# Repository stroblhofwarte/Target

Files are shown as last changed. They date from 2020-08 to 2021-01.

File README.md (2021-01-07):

# TargetClient
Target(Astronomy) is a small WiFi-Handbox to control a telecope mount via INDI. 
This box is running with battery and does not have any wire to the telecope mount. 
This box consists out of a electronic board, a ESP8266 firmware (arduino IDE) and a 
Qt5 application bridging the handbox to the INDI mount. The handbox provides four keys 
for N,S,W and E, one slew speed key with three LED's and a function key which change 
the N,S,W and E key to Focuser 1 in and out and Focuser 2 in and out 
(not tested yet, I don't have any motor focuser).

# Prerequist (Ubuntu)

```
sudo apt install build-essential
sudo apt install cmake
sudo apt install qt5-default
sudo apt install zlib1g-dev
sudo apt install libcfitsio-dev
```
Installation of the INDI lib development package:
```
sudo apt-add-repository ppa:mutlaqja/ppa
sudo apt update
sudo apt install libindi-dev
```

# How to build

```
cd ~/_develop/

git clone https://github.com/stroblhofwarte/Target.git

mkdir -p ~/_develop/build/targetclient

cd ~/_develop/build/targetclient

cmake -DCMAKE_INSTALL_PREFIX=/usr -DCMAKE_BUILD_TYPE=Release ~/_develop/Target/targetclient

make -j4

sudo cp TargetClient <WHERE/EVER/YOU/WANT>
```

# ASCOM TargetBridge

The new Version of the Target_Astronomy_.ino firmware (from 6.01.2021, ./targetclient/arduino/Target_Astronomy_) is supported by the ASCOM TargetBridge. This version of the firmware is
not supported by the INDI driver anymore. 
The ASCOM TargetBridge adds support for a Win10 based observatory setup. With the TargetBridge application the Target handcontroler 
box can be used to control the mount and the focuser together with the imaging software (e.g. N.I.N.A.). To reach this the ASCOM Hub must
be setup for devices not supporting a multiconnection. The ASCOM Hub must be setup only once. After setup the TargetBridge and/or the imaging
software will startup the hub automatically.

For some convenience four focuser positions (for absolute focuser only) can be marked. This can be used to switch the focal plane between a 
imaging setup with CCD and a visual setup easily.

The ASCOM TargetBridge is written in C# (VisualStudio 2019) and requires the ASCOM development libs to compile properly. 
An precompiled msi package will follow soon.

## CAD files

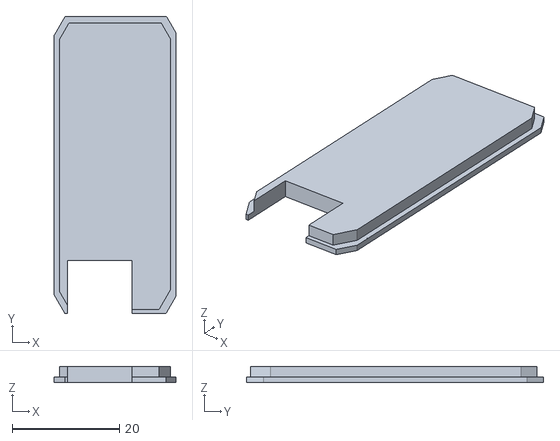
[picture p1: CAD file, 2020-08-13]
electronic/Front.stl
22.7 x 55.3 x 3.00

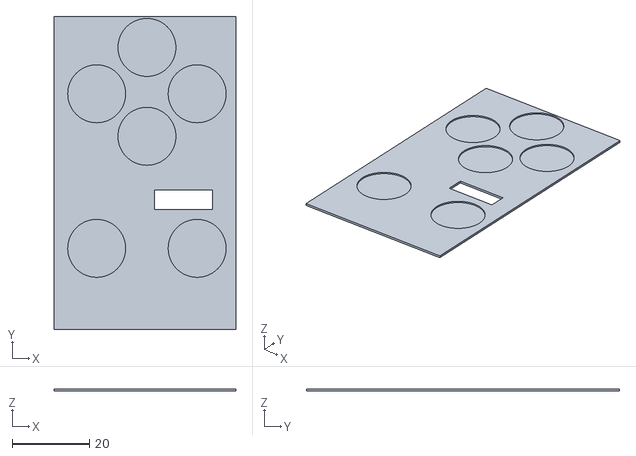
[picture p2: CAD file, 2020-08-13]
electronic/keymap.stl
47.0 x 81.0 x 0.6

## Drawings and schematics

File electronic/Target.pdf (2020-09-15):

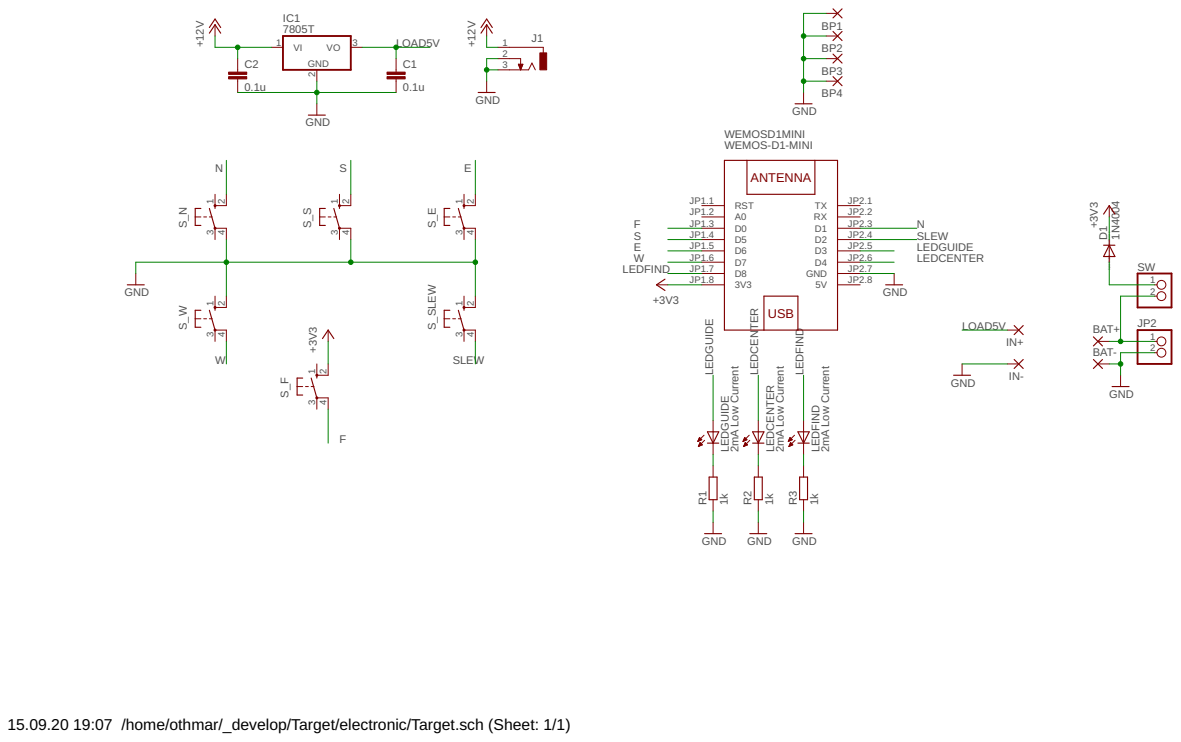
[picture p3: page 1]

15.09.20 19:07 /home/othmar/_develop/Target/electronic/Target.sch (Sheet: 1/1)

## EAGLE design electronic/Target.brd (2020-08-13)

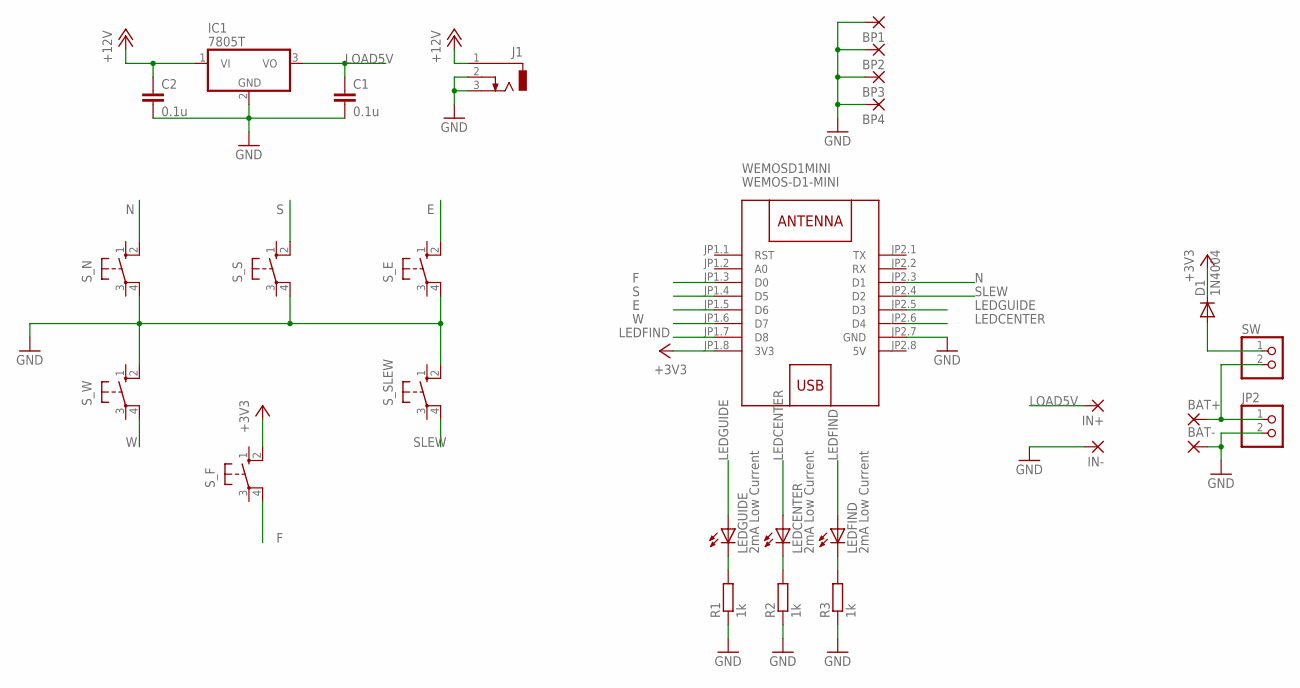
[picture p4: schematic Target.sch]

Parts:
BAT+: 2,15/1,0
BAT-: 2,15/1,0
BP1, BP2, BP3, BP4: 3,81/1,4
C1, C2: 0.1u; C025_050-025X075
D1: 1N4004; DO41-10
IC1: 7805T; TO220H
IN+: 2,15/1,0
IN-: 2,15/1,0
J1: DCJ0303
JP2: PINHD-1X2; 1X02
LEDCENTER: 2mA Low Current; LED3MM
LEDFIND: 2mA Low Current; LED3MM
LEDGUIDE: 2mA Low Current; LED3MM
R1, R2, R3: 1k; 0204/7
SW: PINHD-1X2; 1X02
S_E: 40-XX; B3F-40XX
S_F: 40-XX; B3F-40XX
S_N: 40-XX; B3F-40XX
S_S: 40-XX; B3F-40XX
S_SLEW: 40-XX; B3F-40XX
S_W: 40-XX; B3F-40XX
WEMOSD1MINI: WEMOS-D1-MINI

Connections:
5V: WEMOSD1MINI.JP2.8 (5V)
+3V3: D1.C, S_F.2 (S1), WEMOSD1MINI.JP1.8 (3V3)
+12V: C2.1, IC1.1 (VI), J1.1
E: S_E.2 (S1), WEMOSD1MINI.JP1.5 (D6)
F: S_F.4 (P1), WEMOSD1MINI.JP1.3 (D0)
GND: BAT-.1, BP1.1, BP2.1, BP3.1, BP4.1, C1.2, C2.2, IC1.2 (GND), IN-.1, J1.2, J1.3, JP2.2, R1.1, R2.1, R3.1, S_E.4 (P1), S_N.4 (P1), S_S.4 (P1), S_SLEW.2 (S1), S_W.2 (S1), WEMOSD1MINI.JP2.7 (GND)
LEDCENTER: LEDCENTER.A, WEMOSD1MINI.JP2.6 (D4)
LEDFIND: LEDFIND.A, WEMOSD1MINI.JP1.7 (D8)
LEDGUIDE: LEDGUIDE.A, WEMOSD1MINI.JP2.5 (D3)
LOAD5V: C1.1, IC1.3 (VO), IN+.1
N: S_N.2 (S1), WEMOSD1MINI.JP2.3 (D1)
unnamed: LEDGUIDE.K (C), R1.2
unnamed: LEDCENTER.K (C), R2.2
unnamed: LEDFIND.K (C), R3.2
unnamed: BAT+.1, JP2.1, SW.2
unnamed: D1.A, SW.1
S: S_S.2 (S1), WEMOSD1MINI.JP1.4 (D5)
SLEW: S_SLEW.4 (P1), WEMOSD1MINI.JP2.4 (D2)
W: S_W.4 (P1), WEMOSD1MINI.JP1.6 (D7)

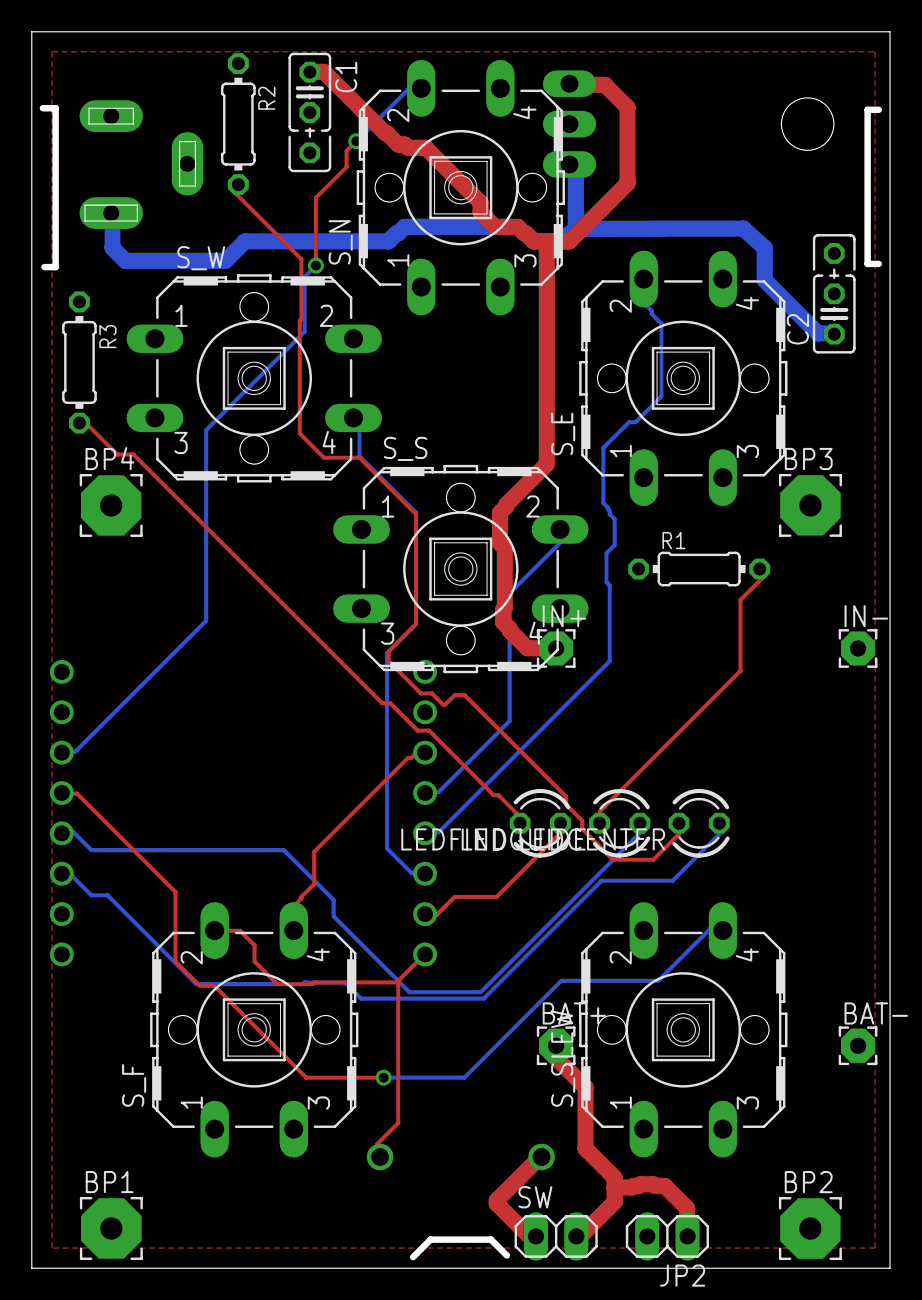
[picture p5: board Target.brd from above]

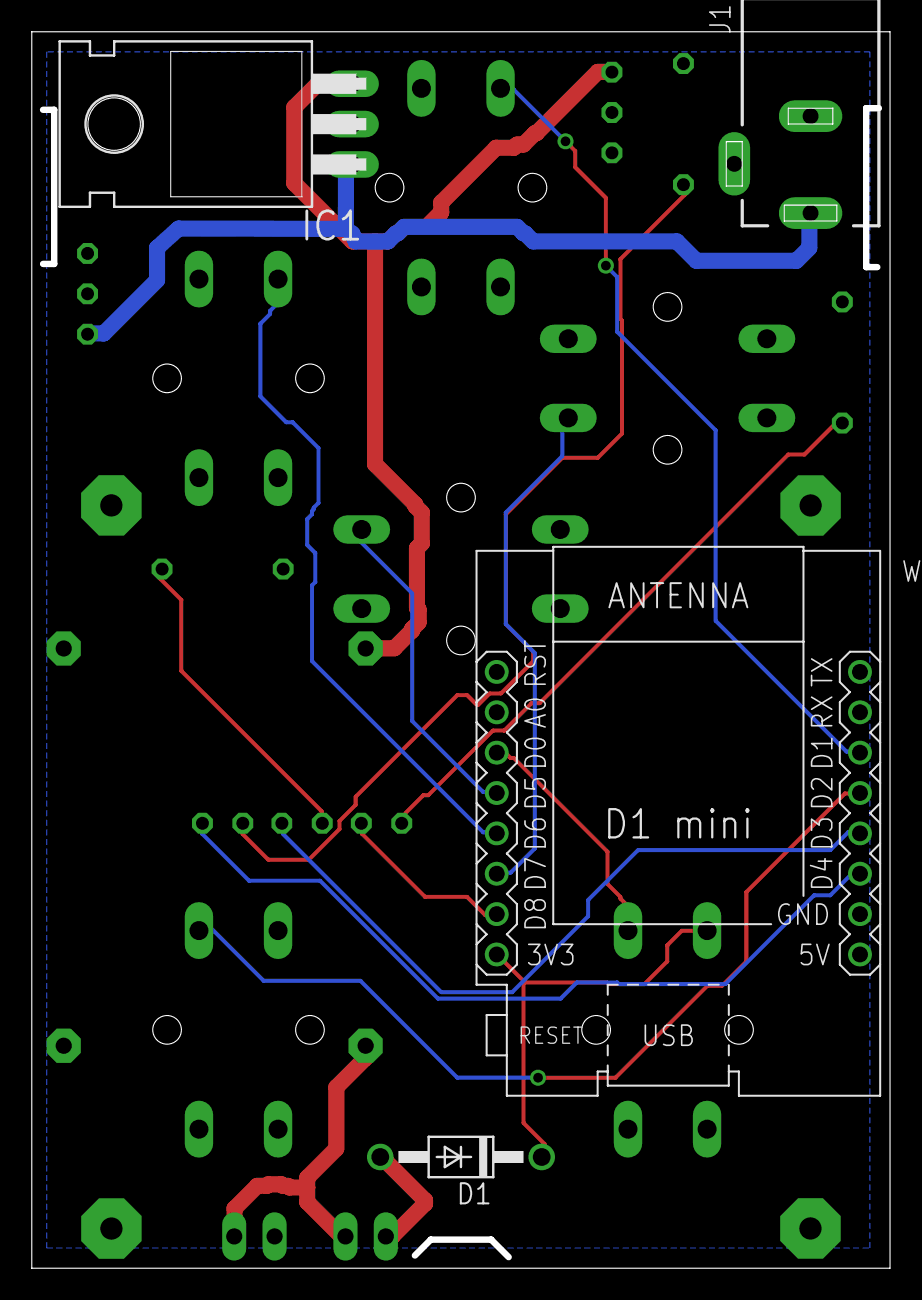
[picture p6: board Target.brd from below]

Board: 2 copper layers, 54.0 x 77.8 mm, 28 parts (4 on the bottom side), 18 nets.

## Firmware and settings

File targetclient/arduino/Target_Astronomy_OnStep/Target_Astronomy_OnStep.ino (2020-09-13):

/****************************************************************************************************************************
 * Target(Astronomy) control box
 * 
 * Software of the handcontrol box connected to a OnStep WiFi board.
 * This program will send the key presses of N,S,W,E,Func and Slew via TCP/IP.
 * 
 * It use the port 9998!
 * 
 * 
 * The startingpoint of this software was the ConfigOnStartup.ino example for ESP8266/ESP32 boards. 
 * 
 * 
 * Orginal Header:
 * 
 * ConfigOnStartup.ino
 * For ESP8266 / ESP32 boards
 *
 * ESP_WiFiManager is a library for the ESP8266/ESP32 platform (https://github.com/esp8266/Arduino) to enable easy
 * configuration and reconfiguration of WiFi credentials using a Captive Portal. Inspired by:
 * http://www.esp8266.com/viewtopic.php?f=29&t=2520
 * https://github.com/chriscook8/esp-arduino-apboot
 * https://github.com/esp8266/Arduino/blob/master/libraries/DNSServer/examples/CaptivePortalAdvanced/
 *
 * Forked from Tzapu https://github.com/tzapu/WiFiManager
 * and from Ken Taylor https://github.com/kentaylor
 * 
 * Built by Khoi Hoang https://github.com/khoih-prog/ESP_WiFiManager
 * Licensed under MIT license
 * Version: 1.0.4
 *
 * Version Modified By   Date      Comments
 * ------- -----------  ---------- -----------
 *  1.0.0   K Hoang      07/10/2019 Initial coding
 *  1.0.1   K Hoang      13/12/2019 Fix bug. Add features. Add support for ESP32
 *  1.0.4   K Hoang      07/01/2020 Use ESP_WiFiManager setHostname feature
 *  1.0.5   K Hoang       15/01/2020 Add configurable DNS feature. Thanks to @Amorphous of https://community.blynk.cc
 *****************************************************************************************************************************/

#include <FS.h>  

 /**************************************************************************************
  * 
  * Changelog:
  * 
  * 24.06.2020: Initial setup of the software.
  * 12.09.2020: Branch for development of a OnStep WiFi client.
  * 
  * 
  * ************************************************************************************/

//#define DEBUG //"Schalter" zum aktivieren

#ifdef DEBUG
#define DEBUG_PRINT(x) Serial.print(x)
#define DEBUG_PRINTLN(x) Serial.println(x)
#define AP_TIMEOUT 30
#else
#define DEBUG_PRINT(x)
#define DEBUG_PRINTLN(x)
#define AP_TIMEOUT 60
#endif
  
//For ESP32, To use ESP32 Dev Module, QIO, Flash 4MB/80MHz, Upload 921600

//Ported to ESP32
#ifdef ESP32
  #include <esp_wifi.h>
  #include <WiFi.h>
  #include <WiFiClient.h>

  #define ESP_getChipId()   ((uint32_t)ESP.getEfuseMac())

  #define LED_ON      HIGH
  #define LED_OFF     LOW  
#else
  #include <ESP8266WiFi.h>          //https://github.com/esp8266/Arduino
  //needed for library
  #include <DNSServer.h>
  #include <ESP8266WebServer.h>  

  #define ESP_getChipId()   (ESP.getChipId())

  #define LED_ON      HIGH
  #define LED_OFF     LOW
#endif

// SSID and PW for Config Portal
String ssid = "TargetHandbox_" + String(ESP_getChipId(), HEX);
const char* password = "88888888";

// SSID and PW for your Router
String Router_SSID;
String Router_Pass;

// Use false if you don't like to display Available Pages in Information Page of Config Portal
// Comment out or use true to display Available Pages in Information Page of Config Portal
// Must be placed before #include <ESP_WiFiManager.h> 
#define USE_AVAILABLE_PAGES     false

#include <ESP_WiFiManager.h>              //https://github.com/khoih-prog/ESP_WiFiManager
#include <ArduinoJson.h>                  //https://github.com/bblanchon/ArduinoJson

/******************************************************************
 * 
 *  Hardwaredefinition for Target(Astronomy):
 *  
 *  
 */

#define K_N           D1
#define K_S           D5
#define K_W           D7
#define K_E           D6
#define K_F           D0
#define K_SLEW        D2
#define LEDGUIDE      D8       // OUT
#define LEDCENTER     D3       // OUT
#define LEDFIND       D4       // OUT

#define KEY_NONE      0
#define KEY_N         1
#define KEY_S         2
#define KEY_W         3
#define KEY_E         4
#define KEY_FUNC      5
#define KEY_F1IN      6
#define KEY_F1OUT     7
#define KEY_F2IN      8
#define KEY_F2OUT     9
#define KEY_SLEW      10

/******************************************************************/
typedef struct
{
    char id[24];
    unsigned char cmd;
} _KEY_DATA;
char MoveNorth[5] = ":Mn#";
char MoveSouth[5] = ":Ms#";
char MoveWest[5] = ":Mw#";
char MoveEast[5] = ":Me#";
char MoveStop[5] = ":Q#";
char Center[5] = ":RC#";
char Guide[5] = ":RG#";
char Find[5] = ":RM#";
char Max[5] = ":RS#";
char Focus1In[5] = ":F+#";
char Focus1Out[5] = ":F-#";
char Focus1Stop[5] = ":FQ#";

int SlewGuide = 1;
int SlewCenter = 2;
int SlewFind = 3;
int SlewMax = 4;

_KEY_DATA g_data;
/******************************************************************
 * Target(Astronomy)
 */
unsigned long g_previousMillis = 0;
const long g_keyScanInterval = 100; //ms
int g_lastKey;

int g_slewrate = SlewMax;

#define ONSTEP_PORT 9998
WiFiClient g_client;
IPAddress IPudp (255, 255, 255, 255); // Sending via broadcast
IPAddress g_host;

char my_ip[32]   = "10.42.0.10";
char my_gw[32]   = "10.42.0.10";
char my_mask[32] = "255.255.255.0";
char my_host[32] = "192.168.0.1";


/*******************************************************************/

//default custom static IP
char static_ip[16] = "192.168.0.42";
char static_gw[16] = "192.168.0.1";
char static_sn[16] = "255.255.255.0";
char static_host[16] = "192.168.0.1";

//flag for saving data
bool g_shouldSaveConfig = false;

//callback notifying us of the need to save config
void saveConfigCallback () {
  DEBUG_PRINTLN("Should save config");
  g_shouldSaveConfig = true;
}


void heartBeatPrint(void)
{
  static int num = 1;

#ifdef DEBUG
  if (WiFi.status() == WL_CONNECTED)
    DEBUG_PRINT("H");        // H means connected to WiFi
  else
    DEBUG_PRINT("F");        // F means not connected to WiFi
#endif

  if (num == 80) 
  {
    DEBUG_PRINTLN();
    num = 1;
  }
  else if (num++ % 10 == 0) 
  {
    DEBUG_PRINT(" ");
  }
} 

void check_status()
{
  static ulong checkstatus_timeout = 0;

  //KH
  #define HEARTBEAT_INTERVAL    10000L
  // Print hearbeat every HEARTBEAT_INTERVAL (10) seconds.
  if ((millis() > checkstatus_timeout) || (checkstatus_timeout == 0))
  {
    heartBeatPrint();
    checkstatus_timeout = millis() + HEARTBEAT_INTERVAL;
  }
}

void ReadFilesystem()
{
  //read configuration from FS json
  Serial.println("mounting FS...");

  if (SPIFFS.begin()) 
  {
    DEBUG_PRINTLN("mounted file system");
    if (SPIFFS.exists("/config.json")) 
    {
      //file exists, reading and loading
      DEBUG_PRINTLN("reading config file");
      File configFile = SPIFFS.open("/config.json", "r");
      if (configFile) 
      {
        DEBUG_PRINTLN("opened config file");
        size_t size = configFile.size();
        // Allocate a buffer to store contents of the file.
        std::unique_ptr<char[]> buf(new char[size]);

        configFile.readBytes(buf.get(), size);
        DynamicJsonBuffer jsonBuffer;
        JsonObject& json = jsonBuffer.parseObject(buf.get());
        json.printTo(Serial);
        if (json.success()) 
        {
          DEBUG_PRINTLN("\nparsed json");
          if(json["ip"]) 
          {
            DEBUG_PRINTLN("setting custom ip from config");
            strcpy(static_ip, json["ip"]);
            strcpy(static_gw, json["gateway"]);
            strcpy(static_sn, json["subnet"]);
            strcpy(static_host, json["host"]);
            DEBUG_PRINTLN(static_ip);
          } 
#ifdef DEBUG
          else {
            DEBUG_PRINTLN("no custom ip in config");
          }
#endif
        } 
#ifdef DEBUG
        else {
          DEBUG_PRINTLN("failed to load json config");
        }
#endif
      }
    }
  } 
#ifdef DEBUG
  else {
    Serial.println("failed to mount FS");
  }
#endif
  //end read
}

void setup() 
{
  /* Target(Astronomy) hardware setup */


  pinMode(K_N,      INPUT_PULLUP);
  pinMode(K_S,      INPUT_PULLUP);
  pinMode(K_W,      INPUT_PULLUP);
  pinMode(K_E,      INPUT_PULLUP);
  pinMode(K_SLEW,   INPUT_PULLUP);
  pinMode(K_F,      INPUT_PULLDOWN_16);

  pinMode(LEDGUIDE,   OUTPUT);
  pinMode(LEDCENTER,  OUTPUT);
  pinMode(LEDFIND,     OUTPUT);

  /************************************/
  
  Serial.begin(115200);
  DEBUG_PRINTLN("\nStarting");
  ReadFilesystem();

 
  unsigned long startedAt = millis();

  // Turn on all LED's in AP mode
  digitalWrite(LEDGUIDE, LED_ON); 
  digitalWrite(LEDCENTER, LED_ON); 
  digitalWrite(LEDFIND, LED_ON); 
  
  //Local intialization. Once its business is done, there is no need to keep it around
  // Use this to default DHCP hostname to ESP8266-XXXXXX or ESP32-XXXXXX
  ESP_WiFiManager ESP_wifiManager("Target");
  
  IPAddress _ip,_gw,_sn;
  _ip.fromString(static_ip);
  _gw.fromString(static_gw);
  _sn.fromString(static_sn);
  g_host.fromString(static_host);
  DEBUG_PRINTLN(_ip);
  DEBUG_PRINTLN(_gw);
  DEBUG_PRINTLN(_sn);
  DEBUG_PRINTLN(g_host);
  
  Router_SSID = ESP_wifiManager.WiFi_SSID();
  Router_Pass = ESP_wifiManager.WiFi_Pass();
  //Check if there is stored WiFi router/password credentials.
  //If not found, device will remain in configuration mode until switched off via webserver.
  DEBUG_PRINTLN("Opening configuration portal.");
  
  // SSID to uppercase 
  ssid.toUpperCase();  
 
  // For some unknown reason webserver can only be started once per boot up 
  // so webserver can not be used again in the sketch.
  #define WIFI_CONNECT_TIMEOUT        30000L
  #define WHILE_LOOP_DELAY            200L
  #define WHILE_LOOP_STEPS            (WIFI_CONNECT_TIMEOUT / ( 3 * WHILE_LOOP_DELAY ))
  
  startedAt = millis();
  
  while ( (WiFi.status() != WL_CONNECTED) && (millis() - startedAt < WIFI_CONNECT_TIMEOUT ) )
  {   
   
    WiFi.mode(WIFI_STA);
    WiFi.persistent (true);
    // We start by connecting to a WiFi network
    
    DEBUG_PRINT("Connecting to ");
    DEBUG_PRINTLN(Router_SSID);
    WiFi.config(_ip, _gw, _sn);
    WiFi.begin(Router_SSID.c_str(), Router_Pass.c_str());
    

    int i = 0;
    while((!WiFi.status() || WiFi.status() >= WL_DISCONNECTED) && i++ < WHILE_LOOP_STEPS)
    {
      delay(WHILE_LOOP_DELAY);
    }    
  }

  DEBUG_PRINT("After waiting ");
  DEBUG_PRINT((millis()- startedAt) / 1000);
  DEBUG_PRINTLN(" secs more in setup(), connection result is ");

  if (WiFi.status() == WL_CONNECTED)
  {
    DEBUG_PRINT("connected. Local IP: ");
    DEBUG_PRINTLN(WiFi.localIP());
    SetSlewLed();
    
    /*****************************************************
     * Startup UDP communication
     */
    ssid.toCharArray(g_data.id, sizeof(g_data.id)); // Fill the unique id of this handbox to the command structure 
    g_client.connect(g_host, ONSTEP_PORT);
  }
  //else
  //  Serial.println(ESP_wifiManager.getStatus(WiFi.status()));
}

#define KEY_NONE      0
#define KEY_N         1
#define KEY_S         2
#define KEY_W         3
#define KEY_E         4
#define KEY_FUNC      5
#define KEY_F1IN      6
#define KEY_F1OUT     7
#define KEY_F2IN      8
#define KEY_F2OUT     9
#define KEY_SLEW      10

int ScanKeyboard()
{
    if(digitalRead(K_F) == HIGH)
    {
      // Function key is pressed, this key has no meaning
      // without another key but change the meaning of the
      // other keys.
      if(digitalRead(K_N) == LOW)
        return KEY_F1IN;
      if(digitalRead(K_S) == LOW)
        return KEY_F1OUT;
      if(digitalRead(K_W) == LOW)
        return KEY_F2IN;
      if(digitalRead(K_E) == LOW)
        return KEY_F2OUT;
      
    }
    else
    {
      if(digitalRead(K_N) == LOW)
        return KEY_N;
      if(digitalRead(K_S) == LOW)
        return KEY_S;
      if(digitalRead(K_W) == LOW)
        return KEY_W;
      if(digitalRead(K_E) == LOW)
        return KEY_E;
      if(digitalRead(K_E) == LOW)
        return KEY_E;
      if(digitalRead(K_SLEW) == LOW)
        return KEY_SLEW;
    } 
    return KEY_NONE;
}

void SendCommand(char *cmd)
{
  if(!g_client.connected())
  {
    DEBUG_PRINTLN("Client not connected:");
    digitalWrite(LEDGUIDE, LED_ON); 
    digitalWrite(LEDCENTER, LED_ON); 
    digitalWrite(LEDFIND, LED_ON); 
    g_client.connect(g_host, ONSTEP_PORT);
  }
  if(g_client.connected())
  {
    char buf[200];
    DEBUG_PRINTLN("Connected!");
    SetSlewLed();
    // Client handling code
    DEBUG_PRINTLN(cmd);
    g_client.println(cmd);
  }
#ifdef DEBUG
  else
    DEBUG_PRINTLN("no!");
#endif
}

void SetSlewLed()
{
  if(g_slewrate == SlewGuide)
  {
    digitalWrite(LEDGUIDE, LED_ON); 
    digitalWrite(LEDCENTER, LED_OFF); 
    digitalWrite(LEDFIND, LED_OFF); 
  }
  if(g_slewrate == SlewCenter)
  {
    digitalWrite(LEDGUIDE, LED_OFF); 
    digitalWrite(LEDCENTER, LED_ON); 
    digitalWrite(LEDFIND, LED_OFF); 
  }
  if(g_slewrate == SlewFind)
  {
    digitalWrite(LEDGUIDE, LED_OFF); 
    digitalWrite(LEDCENTER, LED_OFF); 
    digitalWrite(LEDFIND, LED_ON); 
  }
  if(g_slewrate == SlewMax)
  {
    digitalWrite(LEDGUIDE, LED_OFF); 
    digitalWrite(LEDCENTER, LED_OFF); 
    digitalWrite(LEDFIND, LED_OFF); 
  }
}


int SetSlewRate()
{
  if(g_slewrate == SlewGuide)
  {
    g_slewrate = SlewCenter;
  }
  else if(g_slewrate == SlewCenter)
  {
    g_slewrate = SlewFind;
  }
  else if(g_slewrate == SlewFind)
  {
    g_slewrate = SlewMax;
  }
  else if(g_slewrate == SlewMax)
  {
    g_slewrate = SlewGuide;
  }

  if(g_slewrate == SlewGuide)
  {
    DEBUG_PRINTLN("GUIDE");
    SendCommand(Guide);
  }
  if(g_slewrate == SlewCenter)
  {
    DEBUG_PRINTLN("CENTER");
    SendCommand(Center);
  }
  if(g_slewrate == SlewFind)
  {
    DEBUG_PRINTLN("FIND");
    SendCommand(Find);
  }
  if(g_slewrate == SlewMax)
  {
    DEBUG_PRINTLN("MAX");
    SendCommand(Max);
  }
  SetSlewLed();
  return g_slewrate;
}

void loop() 
{
  unsigned long currentMillis = millis();

  // Check for configuration portal startup
  if(digitalRead(K_N) == LOW && digitalRead(K_S) == LOW && digitalRead(K_SLEW) == LOW)
  {
      for(int fl = 0; fl < 5; fl++)
      {
         // Flash for user information
         digitalWrite(LEDGUIDE, LED_OFF); 
         digitalWrite(LEDCENTER, LED_OFF); 
         digitalWrite(LEDFIND, LED_OFF); 
         delay(300);
         // Turn led on.
         digitalWrite(LEDGUIDE, LED_ON); 
         digitalWrite(LEDCENTER, LED_ON); 
         digitalWrite(LEDFIND, LED_ON); 
         delay(300);
      }
      
      ESP_WiFiManager ESP_wifiManager("Target");
      ESP_WMParameter param_my_ip  ("IP Address", "IP Address", my_ip,   33);
      ESP_WMParameter param_my_gw  ("Gateway",    "Gateway",    my_gw,   33);
      ESP_WMParameter param_my_mask("Netmask",    "Netmask",    my_mask, 33);
      ESP_WMParameter param_my_host("Host",    "Host",    my_host, 33);
  
      //set config save notify callback
      ESP_wifiManager.setSaveConfigCallback(saveConfigCallback);
      ESP_wifiManager.addParameter(&param_my_ip);
      ESP_wifiManager.addParameter(&param_my_gw);
      ESP_wifiManager.addParameter(&param_my_mask);
      ESP_wifiManager.addParameter(&param_my_host);
  
      ESP_wifiManager.setMinimumSignalQuality(-1);
      //Check if there is stored WiFi router/password credentials.
      //If not found, device will remain in configuration mode until switched off via webserver.
      DEBUG_PRINTLN("Opening configuration portal. ");
      Router_SSID = ESP_wifiManager.WiFi_SSID();
      if (Router_SSID != "")
      {
        ESP_wifiManager.setConfigPortalTimeout(60); //If no access point name has been previously entered disable timeout.
        DEBUG_PRINTLN("Got stored Credentials. Timeout 60s");
      }
      
      //it starts an access point
      //and goes into a blocking loop awaiting configuration
      ESP_wifiManager.startConfigPortal((const char *) ssid.c_str(), password);

      strncpy(my_ip,    param_my_ip.getValue(),   sizeof(my_ip));
      strncpy(my_gw,    param_my_gw.getValue(),   sizeof(my_gw));
      strncpy(my_mask,  param_my_mask.getValue(),  sizeof(my_mask));
      strncpy(my_host,  param_my_host.getValue(),  sizeof(my_host));

      DEBUG_PRINTLN("saving config");
      DynamicJsonBuffer jsonBuffer;
      JsonObject& json = jsonBuffer.createObject();
     
      json["ip"]      = my_ip;
      json["gateway"] = my_gw;
      json["subnet"]  = my_mask;
      json["host"]  = my_host;
  
      File configFile = SPIFFS.open("/config.json", "w");
#ifdef DEBUG
      if (!configFile) {
        DEBUG_PRINTLN("failed to open config file for writing");
      }
#endif
      json.prettyPrintTo(Serial);
      json.printTo(configFile);
      configFile.close();
      //end save
 
      // Turn led off.
      digitalWrite(LEDGUIDE, LED_OFF); 
      digitalWrite(LEDCENTER, LED_OFF); 
      digitalWrite(LEDFIND, LED_OFF); 
    
  }
  if (currentMillis - g_previousMillis >= g_keyScanInterval)
  {
      g_previousMillis = currentMillis;
      int key = ScanKeyboard();
      
      if(key == KEY_N && g_lastKey != key)
      {
        DEBUG_PRINTLN("KEY_N");
        // New key press for North
        SendCommand(MoveNorth);
        g_lastKey = key;
      }
      else if(key == KEY_S && g_lastKey != key)
      {
        DEBUG_PRINTLN("KEY_S");
        // New key press for South
        SendCommand(MoveSouth);
        g_lastKey = key;
      }
      else if(key == KEY_W && g_lastKey != key)
      {
        DEBUG_PRINTLN("KEY_W");
        // New key press for West
        SendCommand(MoveWest);
        g_lastKey = key;
      }
      else if(key == KEY_E && g_lastKey != key)
      {
        DEBUG_PRINTLN("KEY_E");
        // New key press for East
        SendCommand(MoveEast);
        g_lastKey = key;
      }
      else if(key == KEY_SLEW && g_lastKey != key)
      {
        DEBUG_PRINTLN("KEY_SLEW");
        // Handle slew rate 
        SetSlewRate();
        g_lastKey = key;
      }
      else if(key == KEY_F1IN && g_lastKey != key)
      {
        DEBUG_PRINTLN("KEY_F1IN");
        // New key press for Focus1 IN
        SendCommand(Focus1In);
        g_lastKey = key;
      }
      else if(key == KEY_F1OUT && g_lastKey != key)
      {
        DEBUG_PRINTLN("KEY_F1OUT");
        // New key press for Focus1 OUT
        SendCommand(Focus1Out);
        g_lastKey = key;
      }
      else if(key == KEY_NONE && g_lastKey != KEY_NONE)
      {
        if(g_lastKey == KEY_N || g_lastKey == KEY_S || g_lastKey == KEY_W || g_lastKey == KEY_E)
        {
          DEBUG_PRINTLN("STOP");
          // A mount movement must be stopped
          SendCommand(MoveStop);
        }
        if(g_lastKey == KEY_F1IN || g_lastKey == KEY_F1OUT)
        {
          // A focuser movement must be stopped
          SendCommand(Focus1Stop);
        }
        g_lastKey = key;
      }
  }
  check_status();
}

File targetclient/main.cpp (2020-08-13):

/*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
    Author: Othmar Ehrhardt, 2020
*/

#include "mainwindow.h"
#include <QApplication>

int main(int argc, char *argv[])
{
    QApplication a(argc, argv);
    MainWindow w;
    w.show();

    return a.exec();
}

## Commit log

2020-08-13 Eagle files added
    [Target.brd, Target.sch]
2020-08-13 Add 3D file for the keys
    [keymap.stl]
2020-08-13 §D-File for the housing front added
    [Front.stl]
2020-09-15 PDF of the schematic added
2021-01-06 Add changes for the TargetBridge ASCOM software (Win10). This change is not compatible to the INDI driver anymore.
    [Target_Astronomy_.ino]

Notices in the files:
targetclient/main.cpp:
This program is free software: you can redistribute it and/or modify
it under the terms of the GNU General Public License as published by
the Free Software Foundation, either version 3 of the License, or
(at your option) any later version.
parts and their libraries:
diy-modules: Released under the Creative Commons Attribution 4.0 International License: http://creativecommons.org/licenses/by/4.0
